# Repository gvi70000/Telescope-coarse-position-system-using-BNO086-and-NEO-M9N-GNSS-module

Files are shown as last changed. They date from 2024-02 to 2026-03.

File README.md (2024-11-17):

This article presents the hardware used for the coarse position of a motorized telescope.

Telescope IMU Top

Telescope IMU Bottom

Temperature-RH

The position is given by the onboard 9 axis IMU BNO086 on I2C bus, the position on Earth is determined using NEO-M9N GNSS module on UART.

For astronomical calculation the pressure and temperature of the environment is read using BMP581 pressure and temperature sensor.

The communication with the telescope main controller is done on RS485 using ST485EBDR RS232 to RS485 converter and the level shifting between

3.3V and 5V is done using TXS0104E level shifter.

This device comes equipped also with 64kbyte SPI EEPROM to store user data.

The KiCAD files can be downloaded here.

The C library software for each IC are uploaded in this repository.

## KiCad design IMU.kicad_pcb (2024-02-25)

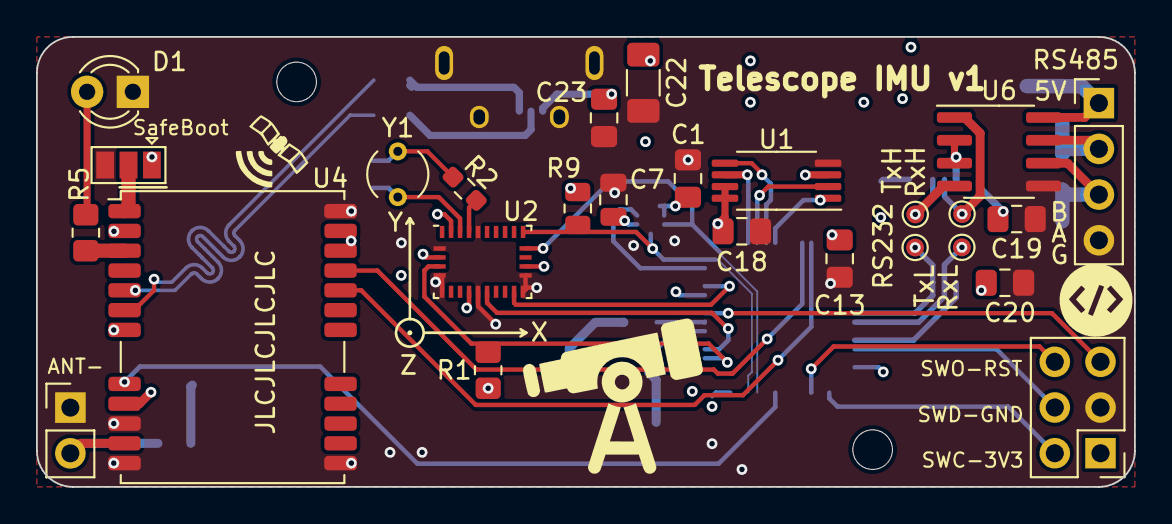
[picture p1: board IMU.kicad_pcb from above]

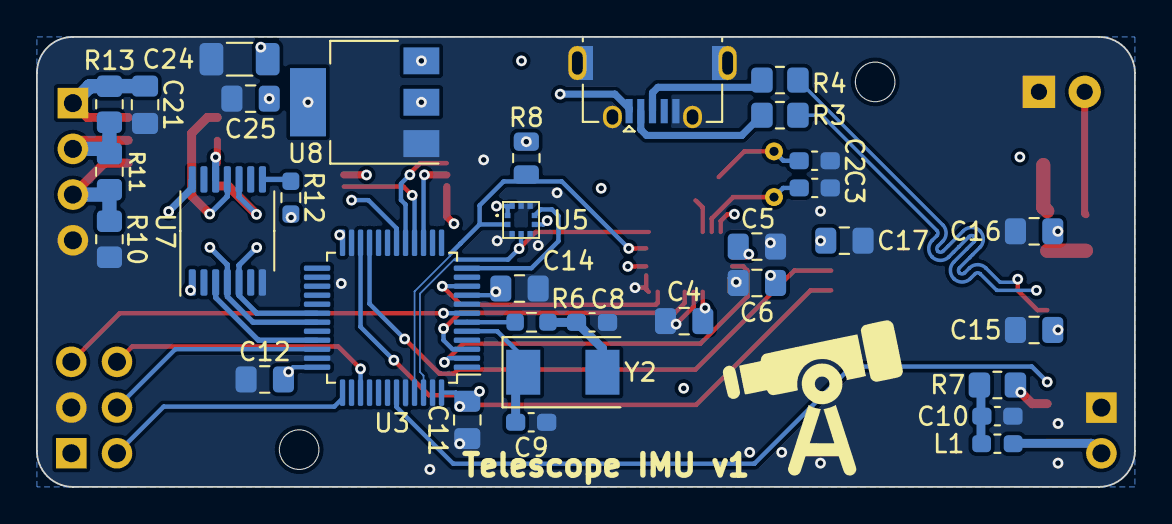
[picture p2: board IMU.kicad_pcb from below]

Board: 4 copper layers, 61.0 x 25.0 mm, 61 parts (33 on the bottom side), 46 nets.

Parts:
C1, C4, C5, C6, C11, C12, C13, C14, C15, C16, C17, C18, C19, C20, C21, C23, C25: 100n; C_0805_2012Metric_Pad1.18x1.45mm_HandSolder
C2, C3: 22p; C_0603_1608Metric_Pad1.08x0.95mm_HandSolder
C7: 100n; C_0805_2012Metric
C8, C9: 18p; C_0603_1608Metric_Pad1.08x0.95mm_HandSolder
C10: 100n; C_0603_1608Metric_Pad1.08x0.95mm_HandSolder
C22, C24: 10u; C_1206_3216Metric_Pad1.33x1.80mm_HandSolder
D1: LED; LED_D3.0mm
H1, H2: MountingHole; MountingHole_2.2mm_M2
J1: Conn_01x02; PinHeader_1x02_P2.54mm_Vertical
J2: Conn_01x04; PinHeader_1x04_P2.54mm_Vertical
J3: USB_B_Micro; USB_Micro-AB_Molex_47590-0001
JP1: Jumper_3_Open; SolderJumper-3_P1.3mm_Open_Pad1.0x1.5mm
L1: 27nH; L_0603_1608Metric_Pad1.05x0.95mm_HandSolder
PRG1: Conn_02x03_Counter_Clockwise; PinHeader_2x03_P2.54mm_Vertical
R1: 10k; R_0805_2012Metric_Pad1.20x1.40mm_HandSolder
R2, R6: 1k; R_0603_1608Metric_Pad0.98x0.95mm_HandSolder
R3, R4: 27; R_0805_2012Metric_Pad1.20x1.40mm_HandSolder
R5, R10, R13: 1k; R_0805_2012Metric_Pad1.20x1.40mm_HandSolder
R7: 10; R_0805_2012Metric_Pad1.20x1.40mm_HandSolder
R8, R9: 2.2k; R_0805_2012Metric
R11: 220; R_0805_2012Metric_Pad1.20x1.40mm_HandSolder
R12: 10k; R_0603_1608Metric_Pad0.98x0.95mm_HandSolder
RX1, RX2: TestPoint; TestPoint_Pad_D1.0mm
TX1, TX2: TestPoint; TestPoint_Pad_D1.0mm
U1: M95256-WMN6P; TSSOP-8_4.4x3mm_P0.65mm
U2: BNO055; LGA-28_5.2x3.8mm_P0.5mm
U3: STM32F302C6Tx; LQFP-48_7x7mm_P0.5mm
U4: NEO-M9N; ublox_NEO
U5: BMP581
U6: ST485EBDR; SOIC-8_3.9x4.9mm_P1.27mm
U7: TXS0104E; TSSOP-14_4.4x5mm_P0.65mm
U8: LD1117; SOT-223-3_TabPin2
Y1: Crystal; Crystal_AT310_D3.0mm_L10.0mm_Vertical
Y2: 8MHz; Crystal_SMD_0603-2Pin_6.0x3.5mm

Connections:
+3V3: C1.1, C5.1, C6.1, C7.1, C11.1, C12.1, C13.1, C14.1, C15.1, C16.1, C17.1, C18.1, C20.1, C24.1, C25.1, JP1.1 (A), PRG1.1, R1.1, R8.2, R9.2, R12.2, U1.3 (~W), U1.7 (~HOLD), U1.8 (VCC), U2.3 (VDD), U2.17 (COM3), U2.28 (VDDIO), U3.9 (VDDA), U3.24 (VDD), U3.36 (VDD), U3.48 (VDD), U4.2 (D_SEL), U4.7 (VDD_USB), U4.22 (V_BCKP), U4.23 (VCC), U5.1 (VDDIO), U5.6 (CSB), U5.10 (VDD), U7.1 (VCCA), U8.2 (VO)
+5V: C19.1, C21.1, C22.1, C23.1, J2.1, J3.1 (VBUS), R13.1, U6.8 (VCC), U7.14 (VCCB), U8.3 (VI)
A: J2.3, R10.1, R11.2, U6.6 (A)
B: J2.2, R11.1, R13.2, U6.7 (B)
BMP_INT: U3.12 (PA2), U5.7 (INT)
BNO_BOOT: R1.2, U2.4 (~BOOT_LOAD_PIN), U3.2 (PC13)
BNO_INT: U2.14 (INT), U3.10 (PA0)
BNO_RST: U2.11 (~RESET), U3.3 (PC14)
CS_MEM: U1.1 (~S), U3.18 (PB0)
D+: J3.3 (D+), R4.1
D-: J3.2 (D-), R3.1
DE_H: U6.2 (~RE), U6.3 (DE), U7.12 (B2)
DE_L: U3.33 (PA12), U7.3 (A2)
GND: C1.2, C2.2, C3.2, C4.2, C5.2, C6.2, C7.2, C8.2, C9.2, C10.1, C11.2, C12.2, C13.2, C14.2, C15.2, C16.2, C17.2, C18.2, C19.2, C20.2, C21.2, C22.2, C23.2, C24.2, C25.2, D1.1 (K), J1.1, J2.4, J3.5 (GND), J3.6 (Shield), JP1.3 (B), PRG1.3, R10.2, U1.4 (VSS), U2.2 (GND), U2.5 (PS1), U2.6 (PS0), U2.10 (BL_IND), U2.15 (GNDIO), U2.16 (GNDIO), U2.25 (GNDIO), U3.8 (VSSA), U3.23 (VSS), U3.35 (VSS), U3.44 (BOOT0), U3.47 (VSS), U4.10 (GND), U4.12 (GND), U4.13 (GND), U4.24 (GND), U5.3 (VSS_1), U5.5 (SDO), U5.8 (VSS_2), U5.9 (VSS_3), U6.5 (GND), U7.7 (GND), U8.1 (GND)
GPS_ANT: J1.2, L1.1, U4.11 (RF_IN)
GPS_RST: U3.43 (PB7), U4.8 (~RESET)
GPS_RX: U3.21 (PB10), U4.21 (RXD/SPI_MOSI)
GPS_TX: U3.22 (PB11), U4.20 (TXD/SPI_MISO)
MISO: U1.2 (Q), U3.16 (PA6)
MOSI: U1.5 (D), U3.17 (PA7)
NRST: PRG1.5, U3.7 (NRST)
unnamed: C2.1, R2.1, Y1.2
unnamed: C8.1, R6.1, Y2.2
unnamed: C10.2, L1.2, R7.2
unnamed: D1.2 (A), R5.2
unnamed: JP1.2 (C), U4.1 (~SAFEBOOT)
unnamed: C4.1, U2.9 (CAP)
unnamed: C3.1, U2.27 (XIN32), Y1.1
unnamed: R2.2, U2.26 (XOUT32)
unnamed: R5.1, U4.3 (TIMEPULSE)
unnamed: R12.1, U7.8 (OE)
OSC_IN: C9.1, U3.5 (PF0), Y2.1
OSC_OUT: R6.2, U3.6 (PF1)
RX_H: RX2.1, U6.1 (RO), U7.11 (B3)
RX_L: RX1.1, U3.31 (PA10), U7.4 (A3)
SCK: U1.6 (C), U3.15 (PA5)
SCL: R8.1, U2.19 (COM1), U3.45 (PB8), U5.2 (SCK)
SDA: R9.1, U2.20 (COM0), U3.46 (PB9), U5.4 (SDI)
SWCLK: PRG1.2, U3.37 (PA14)
SWDIO: PRG1.4, U3.34 (PA13)
SWO: PRG1.6, U3.39 (PB3)
TX_H: TX2.1, U6.4 (DI), U7.10 (B4)
TX_L: TX1.1, U3.30 (PA9), U7.5 (A4)
USB_N: R3.2, U4.5 (USB_DM)
USB_P: R4.2, U4.6 (USB_DP)
VCC_RF: R7.1, U4.9 (VCC_RF)

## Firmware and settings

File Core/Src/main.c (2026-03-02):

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

/* Includes ------------------------------------------------------------------*/
#include "main.h"
#include "crc.h"
#include "dma.h"
#include "i2c.h"
#include "spi.h"
#include "tim.h"
#include "usart.h"
#include "gpio.h"

/* USER CODE BEGIN Includes */
#include <stdio.h>
#include <string.h>
#include "BNO_08x_I2C.h"
#include "NEO_M9N.h"
#include "BMP581.h"
#include "HDC302x.h"
#include "EEPROM_SPI.h"
/* USER CODE END Includes */


void SystemClock_Config(void);
/* USER CODE BEGIN 0 */

// USART1 transmit complete flag — cleared by HAL_UART_TxCpltCallback, polled by transmitFrame()
volatile uint8_t txNotComplete = 0;
// Command received from main controller over USART1
volatile uint8_t crtCmd = 0;

// BMP581 data-ready flag — set by HAL_GPIO_EXTI_Callback on BMP_INT_Pin
volatile uint8_t BMP_Ready = 0;
// BMP581 pressure and temperature result
BMP581_sensor_data_t BMP581_Data;

// BNO086 data-ready flag — set by HAL_GPIO_EXTI_Callback on BNO_INT_Pin
// sensorData and rpy externs come from BNO_08x_I2C.h
volatile uint8_t BNO_Ready = 0;

// HDC302x sensor handles — Address set before HDC302x_Init()
HDC302x_t Sensor1;
HDC302x_t Sensor2;
// HDC302x data-ready flags — set by HAL_GPIO_EXTI_Callback on A1_Pin / A2_Pin
volatile uint8_t HDC1_Ready = 0;
volatile uint8_t HDC2_Ready = 0;
// Timestamp of last HDC302x read, used to enforce HDC_READ_TIME interval
uint32_t readTime;

// Latest HDC302x readings — used to compute avgTemp and avgRH in sendData()
float temp1 = 0.0f;
float temp2 = 0.0f;
float rh1   = 0.0f;
float rh2   = 0.0f;

// GPS new-data flag — set in HAL_UART_RxCpltCallback, cleared in main loop
// myGpsData and gpsData declared in NEO_M9N.h / NEO_M9N.c
volatile uint8_t newGpsData = 0;

// Transmit buffer — aligned(4) so HAL_CRC_Calculate() can safely cast to uint32_t*
// Unaligned 32-bit reads are UB on Cortex-M4
__attribute__((aligned(4))) uint8_t txBuffer[TX_LONG_SIZE];

// EXTI callback — sets sensor ready flags
// NOTE: HAL_GPIO_EXTI_IRQHandler already clears the pending bit. Do NOT call
// __HAL_GPIO_EXTI_CLEAR_IT here; it can re-trigger the interrupt on some STM32F3 silicon.
void HAL_GPIO_EXTI_Callback(uint16_t GPIO_Pin) {
    if (GPIO_Pin == BMP_INT_Pin) {
        BMP_Ready = 1;
    }
    if (GPIO_Pin == BNO_INT_Pin) {
        BNO_Ready = 1;
    }
    if (GPIO_Pin == A1_Pin) {   // HDC Sensor 1 INTDRDY (active-low, FALLING edge)
        HDC1_Ready = 1;
    }
    if (GPIO_Pin == A2_Pin) {   // HDC Sensor 2 INTDRDY (active-low, FALLING edge)
        HDC2_Ready = 1;
    }
}

// Calculate CRC32 over txBuffer[0..length-1] and write the result at CRC_POS
// length must be a multiple of 4; HAL_CRC_Calculate() counts uint32_t words
void calculateAndAppendCRC(uint16_t length) {
    uint32_t crcValue = HAL_CRC_Calculate(&hcrc, (uint32_t *)txBuffer, length / 4);
    txBuffer[CRC_POS]     = (uint8_t)(crcValue & 0xFF);          // CRC LSB
    txBuffer[CRC_POS + 1] = (uint8_t)((crcValue >> 8) & 0xFF);  // CRC MSB
}

// USART1 DMA transmit complete — release transmitFrame() polling loop
void HAL_UART_TxCpltCallback(UART_HandleTypeDef *huart) {
    if (huart->Instance == USART1) {
        txNotComplete = 0;
    }
}

// USART DMA receive complete callback
void HAL_UART_RxCpltCallback(UART_HandleTypeDef *huart) {
    if (huart->Instance == USART1) {
        // Static: DMA writes into this buffer after the callback returns —
        // a local (stack) variable would be freed before DMA finishes
        static uint8_t devRxBuffer[TX_SHORT_SIZE];
        uint8_t data_length = TX_SHORT_SIZE - __HAL_DMA_GET_COUNTER(huart1.hdmarx);
        HAL_UART_DMAStop(&huart1);

        if (data_length > 4) {
            // TODO: parse command from devRxBuffer
        }

        HAL_UART_Receive_DMA(&huart1, devRxBuffer, TX_SHORT_SIZE);
        __HAL_DMA_DISABLE_IT(&hdma_usart1_rx, DMA_IT_HT);
        __HAL_UART_ENABLE_IT(&huart1, UART_IT_IDLE);
    }

    if (huart->Instance == USART3) {
        // DMA TC fires when all RX_BUFFER_LEN=100 bytes are received —
        // one exact UBX-NAV-PVT packet. Re-arm DMA immediately so the next
        // packet starts filling gpsData[] without a gap. No memset needed;
        // DMA overwrites all 100 bytes each transfer.
        __HAL_UART_SEND_REQ(&huart3, UART_RXDATA_FLUSH_REQUEST);
        HAL_UART_Receive_DMA(&huart3, gpsData, RX_BUFFER_LEN);
        __HAL_DMA_DISABLE_IT(&hdma_usart3_rx, DMA_IT_HT);

        // Sync-byte guard: reject mis-aligned transfers that can occur on the
        // very first packet after startup if the module was mid-sentence
        if (gpsData[0] == 0xB5) {
            newGpsData = 1;
        }
    }
}

// Transmit txBuffer over USART1 DMA and block until complete or timeout
void transmitFrame(const uint8_t length) {
    uint32_t startTime = HAL_GetTick();
    txNotComplete = 1;

    HAL_UART_Transmit_DMA(&huart1, txBuffer, length);

    while (txNotComplete) {
        if (HAL_GetTick() - startTime > TIMEOUT_COMM) {
            HAL_UART_AbortTransmit(&huart1);  // Abort on timeout
            MX_USART1_UART_Init();            // Re-initialize UART
            txNotComplete = 0;
            break;
        }
    }
}

// Build and transmit the full sensor data frame over USART1
void sendData(void) {
    // Snapshot GPS data atomically — USART3 DMA ISR can write myGpsData at any
    // point; preemption mid struct-copy yields torn data
    __disable_irq();
    GPS_DATA_t gpsSnapshot = myGpsData;
    __enable_irq();

    txBuffer[COUNT_POS] = LONG_DATA;
    txBuffer[CMD_POS]   = RESPONSE_DATA;

    // Average temperature — include HDC sensors only if they have been read
    float avgTemp     = BMP581_Data.temperature;
    uint8_t tempCount = 1;
    if (temp1 != 0.0f) { avgTemp += temp1; tempCount++; }
    if (temp2 != 0.0f) { avgTemp += temp2; tempCount++; }
    avgTemp /= (float)tempCount;

    // Use memcpy to write multi-byte values into the uint8_t buffer —
    // direct float* casts violate strict aliasing under ARMCC V6
    memcpy(&txBuffer[TEMP_POS],     &avgTemp,               sizeof(float));
    memcpy(&txBuffer[PRESSURE_POS], &BMP581_Data.pressure,  sizeof(float));

    float avgRH = (rh1 + rh2) / 2.0f;
    memcpy(&txBuffer[RH_POS],  &avgRH,       sizeof(float));
    memcpy(&txBuffer[BNO_POS], &rpy,          sizeof(BNO_RollPitchYaw_t));
    memcpy(&txBuffer[GPS_POS], &gpsSnapshot,  sizeof(GPS_DATA_t));

    calculateAndAppendCRC(CRC_POS);
    txBuffer[END_POS] = END_MARKER;
    transmitFrame(TX_LONG_SIZE);
}

// Build and transmit a short status/response message over USART1
void sendMessage(uint8_t msgType) {
    txBuffer[COUNT_POS] = SHORT_DATA;
    txBuffer[CMD_POS]   = msgType;
    calculateAndAppendCRC(CRC_POS_S);
    txBuffer[END_POS_S] = END_MARKER;
    transmitFrame(TX_SHORT_SIZE);
}

/* USER CODE END 0 */

/**
  * @brief  The application entry point.
  * @retval int
  */
int main(void)
{
    /* MCU Configuration -------------------------------------------------------*/

    /* Reset of all peripherals, Initializes the Flash interface and the Systick. */
    HAL_Init();

    /* Configure the system clock */
    SystemClock_Config();

    /* Initialize all configured peripherals */
    MX_GPIO_Init();
    MX_DMA_Init();
    MX_SPI1_Init();
    MX_USART1_UART_Init();
    MX_USART3_UART_Init();
    MX_I2C1_Init();
    MX_TIM2_Init();
    MX_CRC_Init();

    /* USER CODE BEGIN 2 */

    M9N_Reset();
    HDC302x_Reset();

    // Configure BNO086 boot pins — BOOT_On = normal operation (low = DFU mode, 0x52 I2C address)
    BNO_RST_On;
    BNO_BOOT_On;

    // Wait for all sensors to complete power-on sequence
    HAL_Delay(1000);

    // Set fixed frame header bytes
    txBuffer[0] = START_MARKER;
    txBuffer[1] = START_MARKER;

    // Deselect M95512 EEPROM (CS idle-high)
    EEPROM_RELEASE;

    // Start GPS DMA reception
    M9N_Start();

    // Initialize HDC302x Sensor 2
    Sensor2.Address = HDC302X_SENSOR_2_ADDR;
    if (HDC302x_Init(&Sensor2) != HAL_OK) {
        printf("Sensor 2 initialization failed!\n");
    } else {
        printf("Sensor 2 initialized successfully.\n");
    }

    // Initialize HDC302x Sensor 1
    Sensor1.Address = HDC302X_SENSOR_1_ADDR;
    if (HDC302x_Init(&Sensor1) != HAL_OK) {
        printf("Sensor 1 initialization failed!\n");
    } else {
        printf("Sensor 1 initialized successfully.\n");
    }

    // Start HDC302x auto-measurement at 4 Hz LPM0 — sensor measures continuously;
    // HDC302x_ReadData() fetches the latest result from the output register
    HDC302x_StartAutoMeasurement(&Sensor1, HDC302X_CMD_AUTO_MEASUREMENT_4_PER_SECOND_LPM0);
    HDC302x_StartAutoMeasurement(&Sensor2, HDC302X_CMD_AUTO_MEASUREMENT_4_PER_SECOND_LPM0);
    readTime = HAL_GetTick();

    // Initialize BMP581
    if (BMP581_Init() == HAL_OK) {
        sendMessage(RESPONSE_BMP_INIT_OK);
    } else {
        sendMessage(RESPONSE_BMP_INIT_FAIL);
        printf("BMP initialization failed!\n");
    }

	// Initialize BNO086 (currently disabled)
  if (BNO_Init() == HAL_OK) {
      if (BNO_setHighAccuracyMode() != HAL_OK) {
          // Sensor alive but rpy will stay zero
          sendMessage(RESPONSE_BNO_INIT_FAIL);
          printf("BNO high accuracy mode failed!\n");
      } else {
          sendMessage(RESPONSE_BNO_INIT_OK);
      }
  } else {
      sendMessage(RESPONSE_BNO_INIT_FAIL);
      printf("BNO initialization failed!\n");
  }

	HAL_Delay(TIMEOUT_COMM);

    /* USER CODE END 2 */

    /* Infinite loop */
    /* USER CODE BEGIN WHILE */
    while (1)
    {
        // Handle calibration command from main controller
        if (crtCmd == CMD_CALIBRATE) {
            crtCmd = 0;
            if (BNO_calibrateHighAccuracyAndReset() == HAL_OK) {
                sendMessage(RESPONSE_CALIBRATE_OK);
            } else {
                sendMessage(RESPONSE_CALIBRATE_FAIL);
            }
        }

      // BNO086 — update rpy (5 Hz, interrupt-driven)
      // NOTE: do NOT clear BNO_Ready here. waitInt() inside BNO_dataAvailable()
      // finds BNO_Ready set and clears it itself. Clearing it here first causes
      // waitInt() to always time out → rpy never updates.
      // NOTE: isResetOccurred() reads a flag set by processResponse() inside
      if (BNO_Ready) {
          BNO_dataAvailable();    // waitInt() clears BNO_Ready; quaternionUpdate() updates rpy
          if (isResetOccurred()) {
              BNO_setFeature(ROTATION_VECTOR, 200000, 0);
          }
      }

      // BMP581 — update pressure and temperature (4 Hz, interrupt-driven)
      if (BMP_Ready) {
				BMP_Ready = 0;
				BMP581_Get_TempPressData(&BMP581_Data);
      }

      // HDC302x — read humidity and temperature at 4 Hz (HDC_READ_TIME = 250 ms)
      // Auto-measurement runs continuously inside the sensor; ReadData() fetches
      // the latest result from the output register
      if ((HAL_GetTick() - readTime) > HDC_READ_TIME) {
				if (HDC302x_ReadData(&Sensor1) == HAL_OK) {
					temp1 = Sensor1.Data.Temperature;
					rh1   = Sensor1.Data.Humidity;
				}
				if (HDC302x_ReadData(&Sensor2) == HAL_OK) {
					temp2 = Sensor2.Data.Temperature;
					rh2   = Sensor2.Data.Humidity;
				}
				readTime = HAL_GetTick();
      }

      // GPS — process and transmit at 4 Hz (driven by GPS nav rate)
      // Clear flag before processGPS() so a GPS interrupt arriving during
      // sendData() is not lost
      if (newGpsData) {
				newGpsData = 0;
				processGPS();
				sendData();
      }

        /* USER CODE END WHILE */

        /* USER CODE BEGIN 3 */
    }
    /* USER CODE END 3 */
}

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


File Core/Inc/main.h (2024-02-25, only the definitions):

#define BNO_BOOT_Pin GPIO_PIN_13
#define BNO_BOOT_GPIO_Port GPIOC
#define BNO_RST_Pin GPIO_PIN_14
#define BNO_RST_GPIO_Port GPIOC
#define BNO_INT_Pin GPIO_PIN_0
#define BNO_INT_GPIO_Port GPIOA
#define BNO_INT_EXTI_IRQn EXTI0_IRQn
#define BMP_INT_Pin GPIO_PIN_2
#define BMP_INT_GPIO_Port GPIOA
#define BMP_INT_EXTI_IRQn EXTI2_TSC_IRQn
#define CS_MEM_Pin GPIO_PIN_0
#define CS_MEM_GPIO_Port GPIOB
#define GPS_RX_Pin GPIO_PIN_10
#define GPS_RX_GPIO_Port GPIOB
#define GPS_TX_Pin GPIO_PIN_11
#define GPS_TX_GPIO_Port GPIOB
#define GPS_RST_Pin GPIO_PIN_7
#define GPS_RST_GPIO_Port GPIOB
#define BNO_RST_On BNO_RST_GPIO_Port->BSRR = (uint32_t)BNO_RST_Pin;
#define BNO_RST_Off BNO_RST_GPIO_Port->BRR = (uint32_t)BNO_RST_Pin;
#define BNO_BOOT_On BNO_BOOT_GPIO_Port->BSRR = (uint32_t)BNO_BOOT_Pin;
#define BNO_BOOT_Off BNO_BOOT_GPIO_Port->BRR = (uint32_t)BNO_BOOT_Pin;
#define GPS_RST_On GPS_RST_GPIO_Port->BSRR = (uint32_t)GPS_RST_Pin;
#define GPS_RST_Off GPS_RST_GPIO_Port->BRR = (uint32_t)GPS_RST_Pin;
#define START_MARKER						60 // < Start marker for serial
#define END_MARKER							62 // > End marker for serial
#define CMD_CALIBRATE						67 // C Calibrate
#define RESPONSE_CALIBRATE_OK		CMD_CALIBRATE // C Calibrate OK
#define RESPONSE_CALIBRATE_FAIL	99 // c Calibrate command has failed
#define RESPONSE_DATA						68 // D Send sensor data to main board
#define RESPONSE_BMP_INIT_OK		75 // K
#define RESPONSE_BMP_INIT_FAIL	70 // F
#define RESPONSE_BNO_INIT_OK		107 // k
#define RESPONSE_BNO_INIT_FAIL	102 // f
#define DEV_RX_LEN							3
#define START_POS								0
#define CMD_POS									1
#define END_POS									2
#define BMP_POS									END_POS				// 
#define BNO_POS									BMP_POS + 8		// 10 
#define GPS_POS									BNO_POS + 20	// 30 
#define SUM_POS									GPS_POS + 26	// 56
#define DEV_TX_LEN							SUM_POS + 1		// 57
#define TIMEOUT_SEND						100

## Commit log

2024-11-17 Add files via upload
    KiCAD project files (Schematic, board, manufacturing)
2024-11-17 Add files via upload
    Flex PCB for BMP581 and HDC3020

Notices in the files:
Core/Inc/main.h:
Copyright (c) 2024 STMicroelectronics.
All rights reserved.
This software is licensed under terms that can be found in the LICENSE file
